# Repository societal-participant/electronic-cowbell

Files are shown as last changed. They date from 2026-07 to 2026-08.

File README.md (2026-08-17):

# Electronic Cowbell
This repository contains project files and links to parts for a 3D-printed electronic cowbell that I created. 

## About the Cowbell
The electronic cowbell is an ordinary cowbell, except that it makes noise electronically instead of like a simple metal cowbell. Simply turn on the switch, give it a gentle shake, and listen to it respond to your movement like a real cowbell.

It's a wholly unnecessary object to have, but I thought it'd be fun to take something that wasn't electronic and then make it so.

### Required Parts
The following parts are needed to assemble the electronic cowbell:

 - [Adafruit RP2040 Prop-Maker Feather with I2S Audio Amplifier](https://www.adafruit.com/product/5768)
 - [Breadboard-friendly SPDT Slide Switch](https://www.adafruit.com/product/805)
 - [Mini Oval Speaker - 8 Ohm 1 Watt](https://www.adafruit.com/product/3923)
 - [Lithium Ion Polymer Battery with Short Cable - 3.7V 420mAh](https://www.adafruit.com/product/4236)
 - Two 22 gauge wires 
 - [Double-sided foam tape](https://www.amazon.com/dp/B0DJLR75H9)
 - [3D-printed electronic cowbell enclosure](https://www.thingiverse.com/thing:7390052)

## Installing the Cowbell Files
To download the cowbell files, do the following:
 1. On the [main github page](https://github.com/societal-participant/electronic-cowbell), click the **Code** button.
 2. Click **Download ZIP**. This downloads all the project files needed.

To install the cowbell files on your `CIRCUITPY` device, do the following:
 1. Extract the ZIP file you downloaded previously.
 2. In the extracted ZIP, open the **Cowbell_app** folder.
 3. Copy the contents of the **Cowbell_app** folder to the root of your `CIRCUITPY` device. 

## Configuring the Cowbell

### Configuring Motion Settings
Changing the configuration of the motion settings is not necessary and should be done at your own risk. Make a backup of the code.py file before you change the values in case you need to revert the changes.

## Printing the Cowbell
The following print settings are recommended:

 - Infill 100%
 - Tree supports 

The cowbell model has standoffs inside for attaching the Feather, which is the reason supports are needed.

## Assembling the Cowbell
Assembling the cowbell is done in two parts. First, attach the peripherals to the Feather. Then, attach the Feather and the peripherals to the inside of the cowbell.

The following diagram shows where to solder or attach specific parts:


### Soldering the On/Off Switch
You attach the power switch by soldering two wires from the switch to the Feather. To attach the power switch:

1.  Cut off one of the side pins on the power switch (not the middle pin). You should be left with one side pin and the middle pin.
2.  Solder one wire to each pin.
3.  Solder the other ends of the wire to the Feather.
    1.  Solder one wire to the Ground (G) pin.
    2.  Solder the other wire to the Enable pin (EN).
4.  Double-check that the wires are properly soldered.

### Attaching the Speaker
The speaker is attached to the Feather board by using the screw terminals.

1.  Cut the male connector off of the end of the speaker wires.
2.  Unscrew the + and - screw terminals.
3.  Gently strip the ends of the two speaker wires.
4.  Place the red wire in the + terminal and the black wire in the - terminal.
5.  Screw each terminal shut.

### Attaching the Battery
Attach the battery by plugging it in to the battery terminal on the Feather.

### Attaching Everything to the Cowbell
To attach everything to the inside of the cowbell:

 1. Cut 4 small squares of double-sided foam tape.
 2. Place a square in each corner on the back of the Feather.
 3. Peel the protective paper off and stick the Feather to the standoffs inside the cowbell, making sure that the USB-C port is facing the cowbell opening.
 4. Cut small pieces of foam tape for the battery and for the on/off switch.
 5. Place a piece of foam tape on the battery and the on/off switch.
 6. Peel the protective paper off and stick the battery and the on/off switch to the inside of the cowbell. 

## Using the Cowbell

### Turning It On 
To turn on the cowbell, change the switch from off to on.

### Ringing The Cowbell
To ring the cowbell, while it's on, give it a gentle shake.

### Charging the Cowbell
The Feather has a USB-C charging port attached that you can use to charge the cowbell when its battery is low. Simply plug in a USB-C cable to charge it back up. 

> Written with [StackEdit](https://stackedit.io/).
<!--stackedit_data:
eyJoaXN0b3J5IjpbLTE5NDgzNDExNDAsLTExODI5MTM3MywtMT
E2ODYyODE2Myw3Mjg0Nzc2MzMsLTM0NjgwMjA3NiwxNzgzMDcz
MDAwLC02OTEzMTQ5NzQsMTkzOTI0Nzk5NCwxNzUzOTA4NjE2LC
0xODI5MjI1MDczLC0xNTg1NjkxOTczLDExMDY5NzAxNDEsLTQ2
MTYxNDMyNSw4ODk2OTUyMDcsMTA0MjgxMzMzMCwtMTAwNjg5Nz
UzMCwtMTIwMjI2NDI4LDE2Mjc1NzA4MTVdfQ==
-->

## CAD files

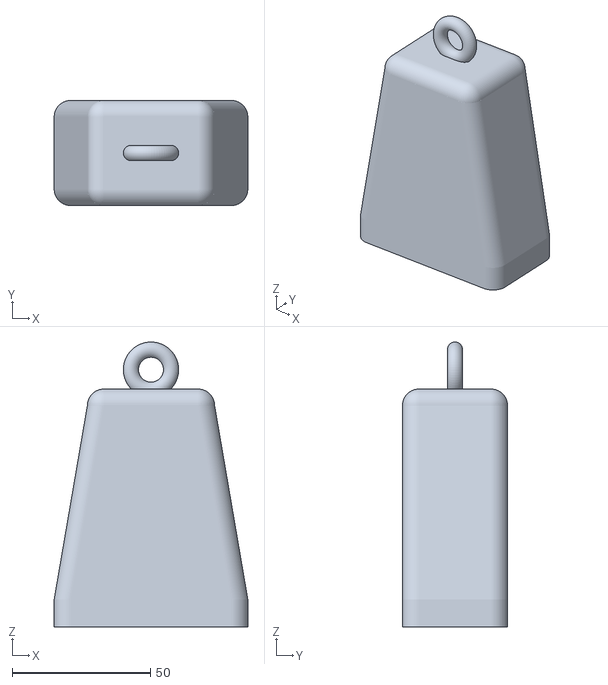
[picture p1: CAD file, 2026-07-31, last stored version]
cowbell.stl
70.0 x 38.0 x 103.0

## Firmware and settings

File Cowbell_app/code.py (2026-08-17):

# SPDX-FileCopyrightText: 2026 Maggie Giles
#
# SPDX-License-Identifier: MIT
"""
Motion-Activated Electronic Cowbell
Adafruit RP2040 Prop-Maker Feather

Uses the board's built-in LIS3DH accelerometer to detect movement and
its built-in I2S amp to play a WAV file through the speaker.

Behavior:
- No movement -> silence
- Movement detected -> play immediately (no delay)
- If another movement is detected while the WAV is still playing, it
  restarts from the beginning -- so the faster/more often you shake it,
  the faster it jingles, tracking your shake rate directly.

NOTE ON VOLUME: The WAV is streamed straight from the
filesystem rather than loading it into RAM. If you want
to change the volume, boost the WAV file ITSELF in Audacity,
then re-export and copy it back onto CIRCUITPY as cowbell.wav.
"""

import time
import board
import audiocore
import audiobusio
import audiomixer
from digitalio import DigitalInOut, Direction
import adafruit_lis3dh

# ----------------- Settings you may want to tune -----------------
WAV_FILE = "cowbell.wav"     # name of your wav file on CIRCUITPY
MOVEMENT_THRESHOLD = 1.5     # m/s^2 of combined change to count as "movement"
                              # WHILE SILENT -- keep this as your normal
                              # sensitivity for a genuine idle-to-shake trigger.
MOVEMENT_THRESHOLD_WHILE_PLAYING = 6.0  # stricter threshold used ONLY while
                              # the wav is already playing. The speaker's own
                              # vibration through the plastic shell can look
                              # like "motion" to the accelerometer and
                              # retrigger itself in a loop, so raising the bar
                              # here specifically filters
                              # out the feedback while still letting a
                              # genuinely hard/fast shake override and
                              # retrigger.
RETRIGGER_COOLDOWN = 0.15    # small debounce ONLY -- just enough to keep a
                              # single shake from double-counting due to
                              # sensor noise. Keep this small so replay rate
                              # can actually track how fast you're shaking.
SAMPLE_RATE = 22050          # must match your wav file's sample rate
CHANNEL_COUNT = 2            # 1 = mono, 2 = stereo -- must match your wav file
# -------------------------------------------------------------------

# Power up the onboard amp + accelerometer rail
external_power = DigitalInOut(board.EXTERNAL_POWER)
external_power.direction = Direction.OUTPUT
external_power.value = True
time.sleep(0.1)  # give the amp a moment to wake up

# Set up the onboard LIS3DH accelerometer
i2c = board.I2C()
int1 = DigitalInOut(board.ACCELEROMETER_INTERRUPT)
lis3dh = adafruit_lis3dh.LIS3DH_I2C(i2c, int1=int1)
lis3dh.range = adafruit_lis3dh.RANGE_2_G

# Set up I2S audio output through the onboard amp
audio = audiobusio.I2SOut(board.I2S_BIT_CLOCK, board.I2S_WORD_SELECT, board.I2S_DATA)
mixer = audiomixer.Mixer(
    voice_count=1,
    sample_rate=SAMPLE_RATE,
    channel_count=CHANNEL_COUNT,
    bits_per_sample=16,
    samples_signed=True,
)
audio.play(mixer)
mixer.voice[0].level = 1.0  # make sure we're not leaving free headroom on the table

_current_wave_file = None


def play_wav():
    """(Re)open and play the wav file from the beginning. Streams from
    the filesystem rather than loading it all into RAM -- works
    regardless of how long the file is."""
    global _current_wave_file
    if _current_wave_file:
        _current_wave_file.close()
    _current_wave_file = open(WAV_FILE, "rb")
    wave = audiocore.WaveFile(_current_wave_file)
    mixer.voice[0].play(wave)


# Baseline reading so we can detect *changes* in acceleration rather than
# absolute values (which always include ~9.8 m/s^2 of gravity on some axis)
last_accel = lis3dh.acceleration
last_trigger_time = -RETRIGGER_COOLDOWN  # allow an immediate first trigger

while True:
    x, y, z = lis3dh.acceleration
    delta = abs(x - last_accel[0]) + abs(y - last_accel[1]) + abs(z - last_accel[2])
    last_accel = (x, y, z)

    # Use the stricter threshold while sound is actively playing, so the
    # speaker's own vibration doesn't retrigger itself in a feedback loop.
    active_threshold = (
        MOVEMENT_THRESHOLD_WHILE_PLAYING if mixer.voice[0].playing else MOVEMENT_THRESHOLD
    )

    now = time.monotonic()
    if delta > active_threshold and (now - last_trigger_time) > RETRIGGER_COOLDOWN:
        last_trigger_time = now
        play_wav()  # plays immediately, restarting from the beginning even
                     # if already playing -- no artificial delay in the way

    time.sleep(0.02)  # tighter poll loop than before, so quick shakes aren't
                        # missed between sensor reads
